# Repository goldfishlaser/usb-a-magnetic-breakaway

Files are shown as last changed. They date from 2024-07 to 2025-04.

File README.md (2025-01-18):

# usb-a-magnetic-breakaway

This repo is for documenting and providing the design requirements for an open-source USB-A magnetic breakaway connector. Originally created to be a solution for BusKill cables. Perhaps you have another reason you want to quickly magnetically detach a USB? Then here's your thing.  This project is a Work In Progress and it welcomes contributors. 

##  What's New?

Updates to goldfishlaser Version:
* Recommend using 4.0 - has latest changes with a new type of pogo receptor
* If continuing to use 3.9 be aware that there are a few issues with it that will need your attention.
* I'm giving a talk at DEF CON! Read about it here: https://crashxblossom.wordpress.com/2024/06/24/defcon32-announcement/ 

## What's in this Repo?

This repo contains full documentation for how to create this gadget. It contains documented 3D print files (SCAD and STL), Bill of Materials, and more. 



Part 1 Video Assembly Instructions: https://youtu.be/HxwEmIUqQ7w?si=xajbAuSA-TxbAlxz
Prototype Assembly Instructions: https://crashxblossom.wordpress.com/2023/07/04/exciting-milestone-in-buskill-usb-a-magnetic-release-open-hardware-project/

#### CAD Files

Directory contains CAD files for the magnetic breakway case if you want to edit the files. *(in development)*

#### STL files

Directory contains 3D print files for the magnetic breakaway case. 

#### Engineering drawings

Directory contains engineering drawings for the magnets which you can provide to a manufacturer for the purpose of ordering the magnets for the magnetic breakway.

#### Magnet_and_PP_Vendor_List.ods

File contains a list of manufacturers that sell magnets, pogo pins, and pogo receptors. 

## License

The contents of this repo are dual-licensed. All code is GPLv3 and all other content is CC-BY-SA.

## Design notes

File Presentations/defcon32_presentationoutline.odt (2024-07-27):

BusKill Defcon32 Demo Lab Outline

I. Introduction (2 mins)
  - Who is BusKill?
  - Project Goal
  - Project Rationale
II. Get to know the audience (2 mins)
  - Raise hand if
    - Have ever heard of BusKill
    - Have a 3D printer
    - Use Kali? Use QubesOS? Use Tails?
III. Software Capabilities (5 mins)
  - Lock screen / Shutdown (less than 1 min)
  - Luks Header Shredder (1 min) forensically proven with bulk extractor
  - Qubes
  - Limitations
IV. Hardware Requirements (3 mins)
  - Establishes physical security from computer to person
  - Disconnects usb easily, but not too easily
  - Able to dissemble for inspection
  - Doesn’t block neighboring ports
V. Supplier Version (1 min)
  - Components list
  - Where to find in Repo
VI. 3D-Printed Version (2 mins)
  - Components list
  - Where to find in Repo
  - Demo
VII. Hardware Development History and Philosophy (10 mins)
        - Parametric design in OpenSCAD
        - Milestones
            - Choosing parts (considerations for pogo pins, receptors, usbs)
            - Trying to splice it, frying the USB drives
            - The magnets (hexagonal, Nstrength, disc/cube)
        - Constraints
        - OpenSCAD code tour
VIII. How to help and FAQ (6 mins)
  - Build it
  - Make the case smaller
  - Make assembly easier
  - Identify cheaper and more easily sourced components
  - Make the code more parametric

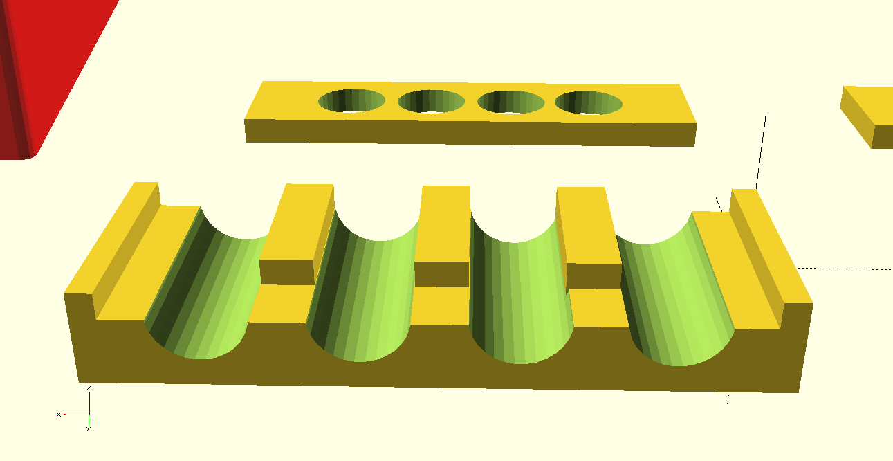
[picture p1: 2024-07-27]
CAD Files/jigdetails.png

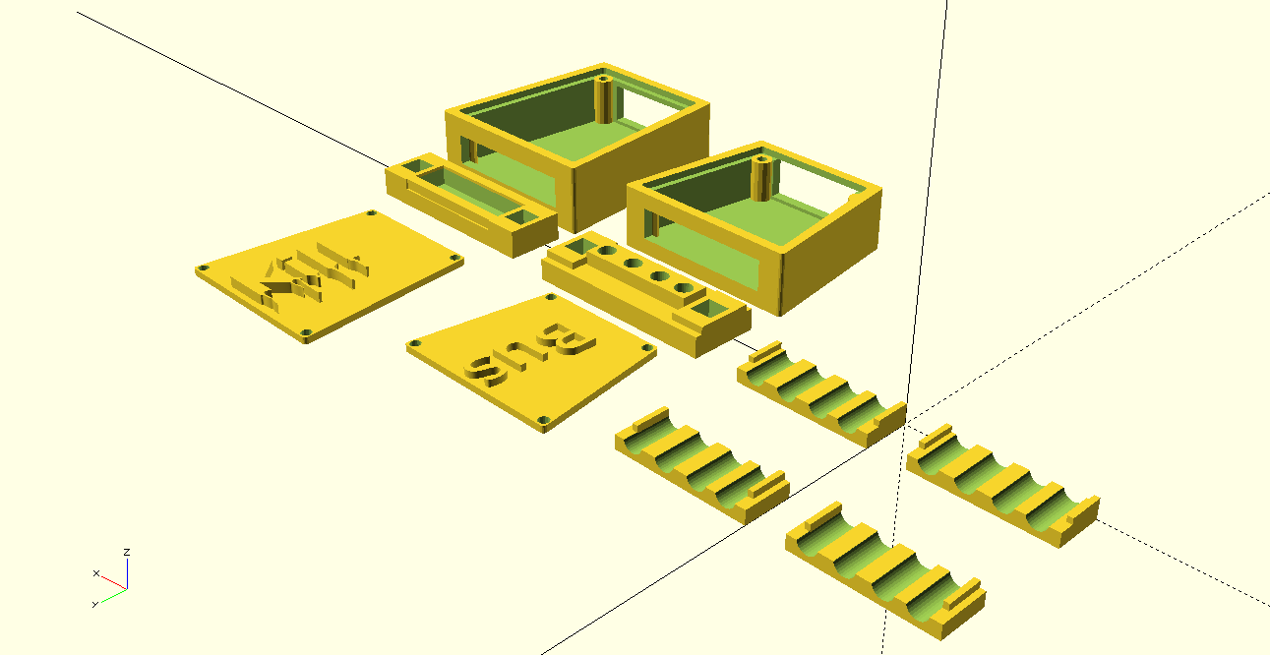
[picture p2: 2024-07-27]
CAD Files/usbamagb_v03.1b.png

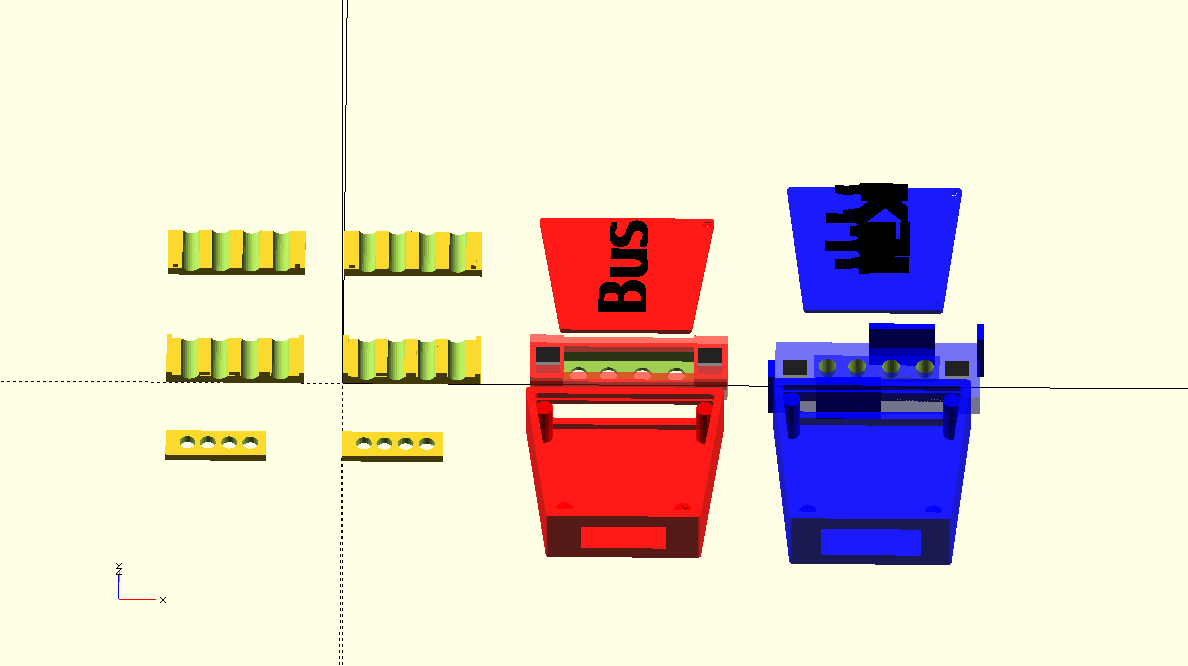
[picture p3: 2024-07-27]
CAD Files/usbamagb_v03.9.png

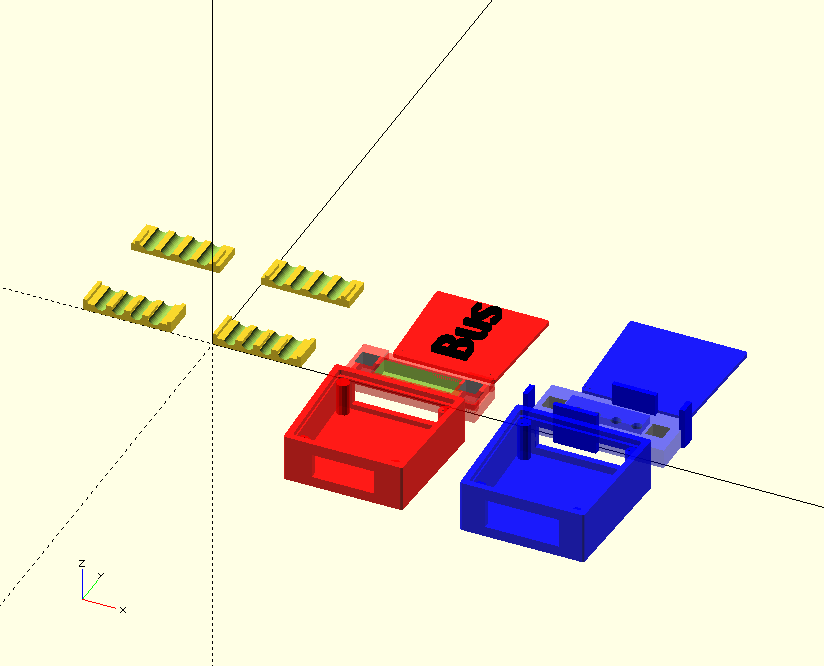
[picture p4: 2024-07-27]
digitalAssets/usbamagb_v04.0.png

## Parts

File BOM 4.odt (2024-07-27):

V 04 Bill of Materials

Open-source USB-A magnetic breakaway connector used in the BusKill laptop kill cord

This BOM is in progress

Component | Base QTY | Link (if applicable)
USB male | 1 | https://amzn.to/43tGNuv
USB female (10 mm) | 1 | https://amzn.to/43tGNuv
Pogo receptors | 4 | https://www.mouser.com/ProductDetail/Mill-Max/3024-0-01-15-00-00-03-0?qs=oyhNEzdnFLo7R2sYdNBgsw%3D%3D
Pogo pins Working height: | 4 | Option 1: https://www.digikey.com/en/products/detail/mill-max-manufacturing-corp/7973-0-15-20-77-14-11-0/10197225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 Option 2: https://www.mouser.com/ProductDetail/Mill-Max/7973-0-15-20-77-14-11-0?qs=%252B6g0mu59x7KQy9JOdoVaiw%3D%3D
3D printed release | 1 | Goldfishlaser Version/CAD Files/intermediary design files/usbamagb_v04.0.stl
3D printed breakaway | 1 | Goldfishlaser Version/CAD Files/intermediary design files/usbamagb_v04.0.stl
1/8” Cube Magnets | 8 | https://www.kjmagnetics.com/proddetail.asp?prod=B222

Estimated Cost Per Unit (without bulk price discounts)

USB Male = .14

USB female = .14

4 x pogo receptors = 4 x .32

4 x pogo pins = 4 x 1.17 (digikey)

or 4 x 1.27 (mouser)

Plastic = 13.76g / 4.61 meters = $8.76

8 x magnets = 8 x .18

USB Extension cord = $8

USB = $10

caribiner = $.80

Total =

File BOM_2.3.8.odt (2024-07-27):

V 2.3.8 Bill of Materials

Open-source USB-A magnetic breakaway connector used in the BusKill laptop kill cord

Component | Base QTY | Link (if applicable)
USB male | 1 | https://amzn.to/43tGNuv
USB female (10 mm) | 1 | https://amzn.to/43tGNuv
Pogo receptors | 4 | https://www.alibaba.com/product-detail/Circular-SMD-Contact-Pad-3-0_62437659039.html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
Pogo pins Working height: 0.298" (7.58mm) | 4 | https://www.digikey.com/en/products/detail/mill-max-manufacturing-corp/0947-0-15-20-77-14-11-0/7402798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
3D printed release | 1 | Goldfishlaser Version/CAD Files/intermediary design files/dengineering_v02.3.8.stl
3D printed breakaway | 1 | Goldfishlaser Version/CAD Files/intermediary design files/dengineering_v02.3.8.stl
3 x 4 mm Disc magnets | 8 | https://www.aliexpress.com/w/wholesale-3x4mm-neodymium-disc-magnets.html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

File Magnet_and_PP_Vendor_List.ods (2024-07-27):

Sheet: Magnets
Prototype Version | Name of Vendor | URL of product page | MOQ | Offer sample service? | Price/magnet | Sizes available (if relevant) | Comments
 |  | Cube magnets
Version >= v.3 | K&J Magnets | https://www.kjmagnetics.com/proddetail.asp?prod=B222 | 1 | N/A | 0.18 | 1/8” | Price/magnet decreases with volume size – Latest Prototype uses these – N52 gold plated may be even better
 |  | Disc magnets DO NOT USE TOO WEAK
Version 2 =< v.2.3.8 | MANHXSCY | https://www.aliexpress.us/item/2251832608106847.html | 100 | no | 0.08 | 4x3 | DO NOT USE – TOO WEAK No longer available at URL - 100pcs Neodymium N35 Dia 4mm X 3mm Strong Magnets Tiny Disc NdFeB Rare Earth For Crafts Models Fridge Sticking magnet 4x3mm
Not used | MANHXSCY | https://www.aliexpress.us/item/2251832608138260.html?gatewayAdapt=glo2usa | 50 | no | 0.175 | 5x4 | No longer available at URL - 50pcs Neodymium N35 Dia 5mm X 4mm Strong Magnets Tiny Disc NdFeB Rare Earth For Crafts Models Fridge Sticking magnet 5x4mm
 | K&J Magnets | https://www.kjmagnetics.com/proddetail.asp?prod=D101-N52 | 100 | N/A | 0.14 | 1/16" dia. x 1/32" thick
 |  | Hex magnets
 | Skyup Magnetics (Ningbo) Co., Ltd. | https://www.alibaba.com/product-detail/12-Years-Experience-factory-producing-rare_62153270553.html | 1 | N/A | $0.02-$0.60 | any
 | Xiamen Balin Magnetic Materials Co., Ltd. | https://www.alibaba.com/product-detail/Powerful-rare-earth-hexagon-neodymium-magnet_62113152666.html | 1 | N/A | $0.05 - $0.50 | any
 | Hangzhou Shengshideng Magnetics Co., Ltd. | https://www.alibaba.com/product-detail/14-Years-Experience-factory-producing-neodymium_60745639237.html | 1 | N/A | $1.00 - $10.00 | any
Version 1 | Dongguan Hj Tech Co., Ltd. | https://www.alibaba.com/product-detail/Hot-Sale-Strong-Electric-Custom-Shape_62489784248.html | 1000 | Yes | $0.03 | any | Placed order for 8 magnets of two sizes. September 9, received order October 10 The stated production time is 15-20 days, and the express delivery time is 7-9 days. There was a small delay, possibly due to holiday. (oops – didn’t realize this shop had a MoQ of 1000, but the customer service was great, and the person I worked with says I and others can order lower quantities if desired)

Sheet: Pogo Pins
Prototype Version | URL of product page | MOQ | Offer sample service? | Price/pin | Type | Comments
Version >= v.2.3.9 | https://www.digikey.com/en/products/detail/mill-max-manufacturing-corp/7973-0-15-20-77-14-11-0/10197225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 | 1 | N/A | $1.13 | 2.66mm STANDARD SPRING-LOADED PIN Contact Spring Through Hole, Solder Cup | Price decreases with order quantity; must pay shipping
Version =< v.2.3.8 | https://www.digikey.com/en/products/detail/mill-max-manufacturing-corp/0947-0-15-20-77-14-11-0/7402798 | 1 | N/A | $0.97 | 7.58mmSTANDARD SPRING-LOADED PIN CONTACT SPRING LOADED SLDR CUP | Price decreases with order quantity
Version =<v3.9 | https://www.alibaba.com/product-detail/Circular-SMD-Contact-Pad-3-0_62437659039.html | 500 | yes | $0.07 | 3.00mm radius contact pad, 2.00mm height, target pin | Ordered 11/28/2020 Received 12/16/2020
Version 4.0 | https://www.mouser.com/ProductDetail/Mill-Max/3024-0-01-15-00-00-03-0?qs=oyhNEzdnFLo7R2sYdNBgsw%3D%3D | 1 | N/A | $0.32 | Circuit Board Hardware - PCB Spring-Loaded Target Contact with Flat Face | Price decreases with order quantity; must pay shipping
Version >= v.2.3.9 | https://www.mouser.com/ProductDetail/Mill-Max/7973-0-15-20-77-14-11-0?qs=%252B6g0mu59x7KQy9JOdoVaiw%3D%3D | 1 | N/A | $1.27 | Circuit Board Hardware - PCB Spring-Loaded Pin with Solder Cup Termination | Price decreases with order quantity; must pay shipping

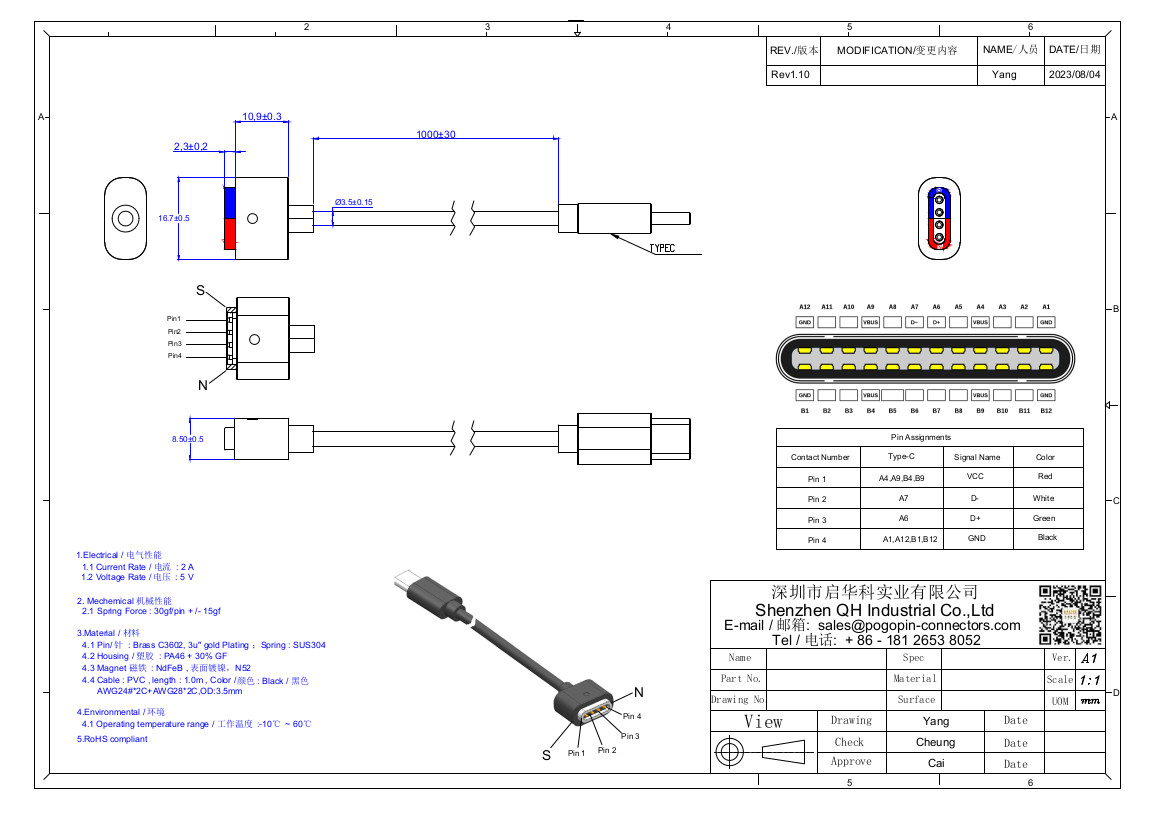
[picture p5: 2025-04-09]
supplier/shenzen_qh_industrial_co/2025-02/2025-02_buskill-usb-c-cable.jpg

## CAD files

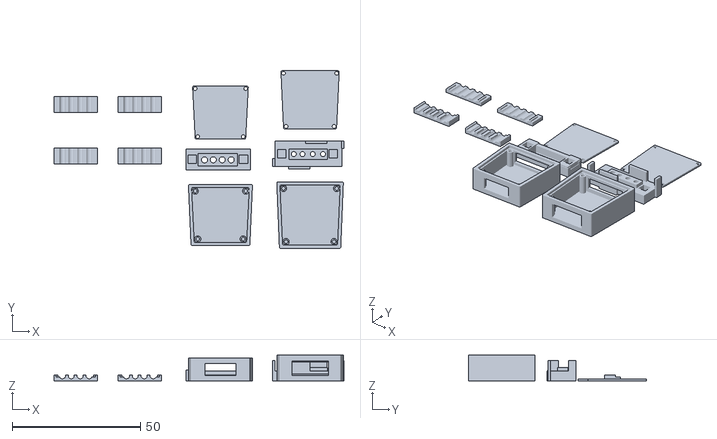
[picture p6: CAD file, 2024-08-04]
STL Files/usbamagb_v04.0.stl
113.2 x 69.4 x 10.0

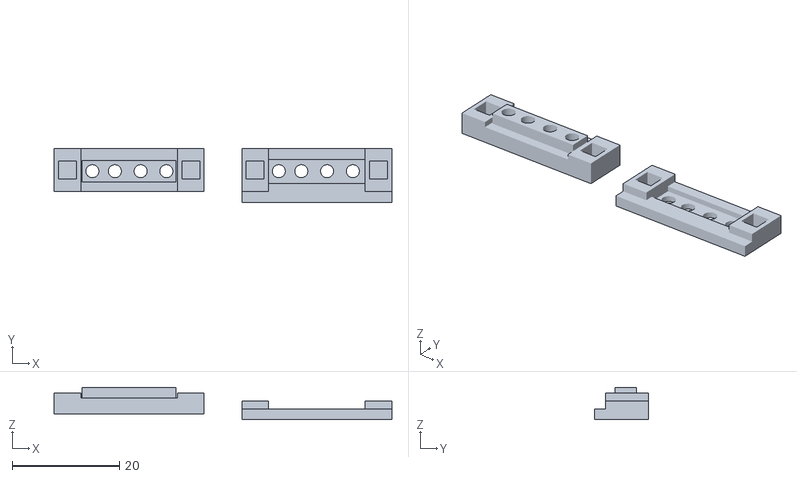
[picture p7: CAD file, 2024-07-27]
STL Files/releaseface_v03.9.stl
63.0 x 10.0 x 6.00

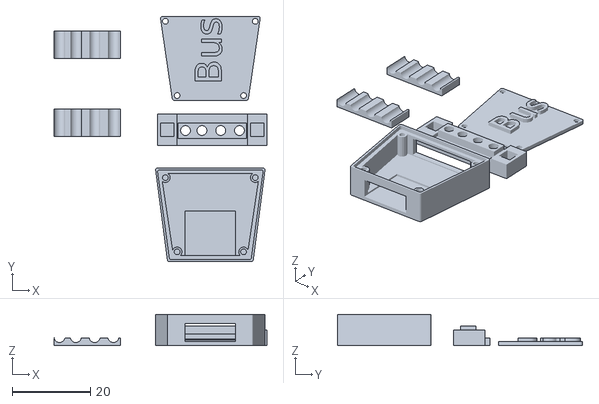
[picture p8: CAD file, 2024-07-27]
STL Files/release_v03.9.2.stl
54.5 x 62.7 x 8.00

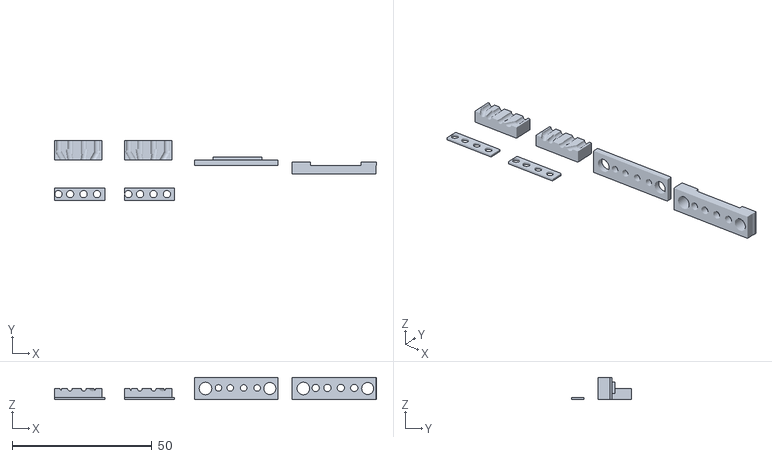
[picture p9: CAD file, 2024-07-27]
STL Files/dengineering_v02.3.9.stl
115.2 x 21.5 x 8.00

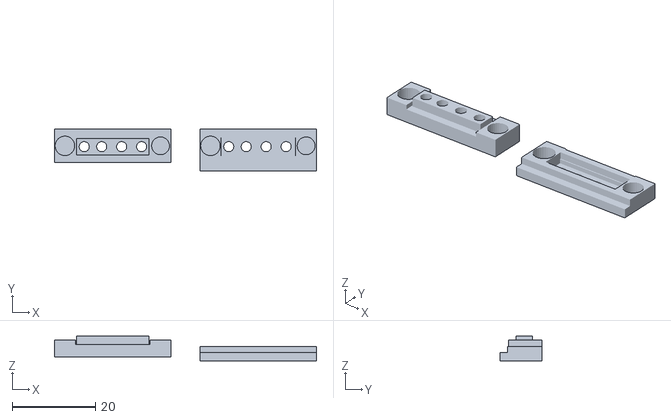
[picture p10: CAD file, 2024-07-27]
STL Files/discface_v03.9.stl
63.0 x 10.0 x 6.00

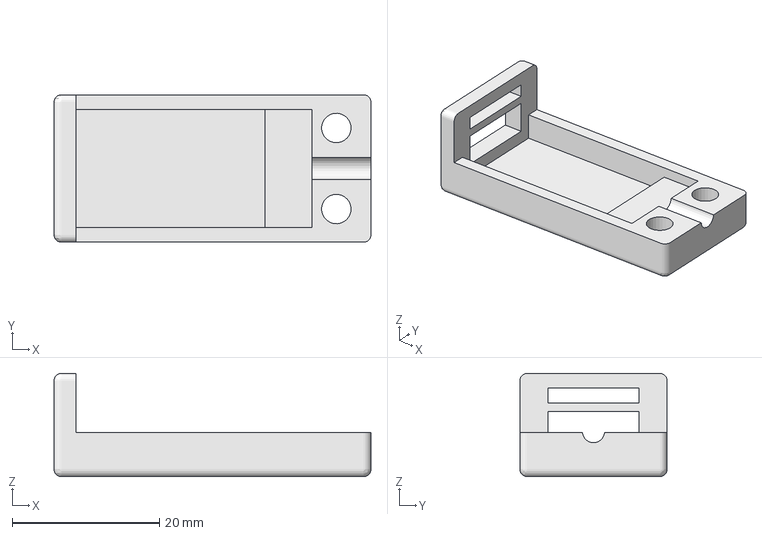
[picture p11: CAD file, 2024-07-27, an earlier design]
CAD Files/FCStd Archive/Shell_Assembly.FCStd
43.0 x 20.0 x 14.0 mm

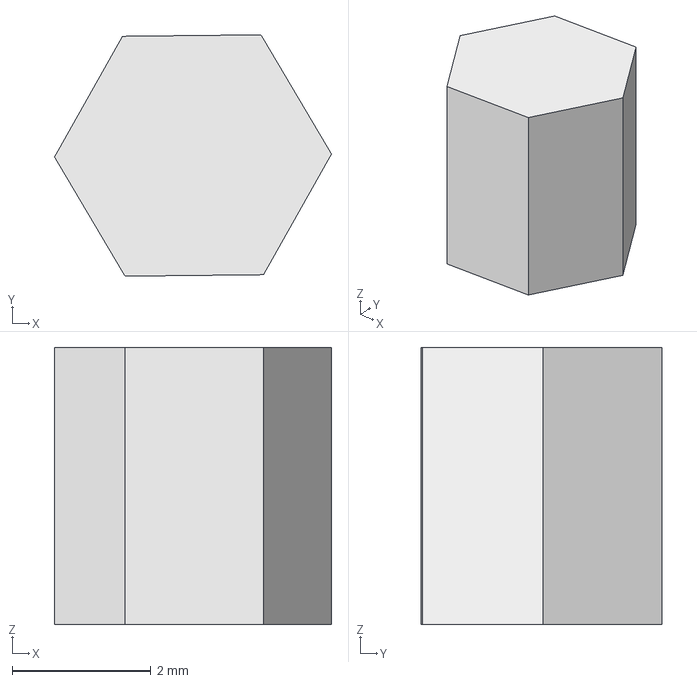
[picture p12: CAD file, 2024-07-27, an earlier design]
CAD Files/FCStd Archive/Magnet_2mm_4mm.fcstd
4.00 x 3.49 x 4.00 mm

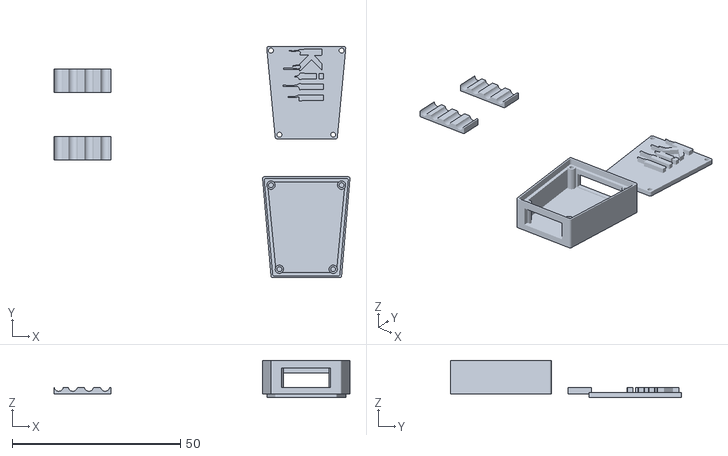
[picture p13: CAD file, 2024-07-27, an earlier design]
STL Files/STL Archive/breakaway_v03.9.stl
88.0 x 68.7 x 11.0

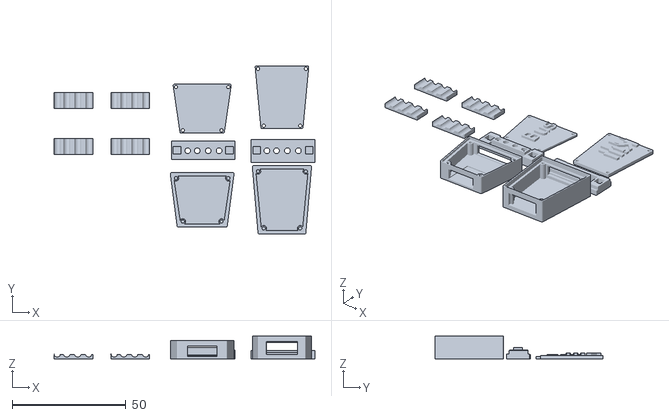
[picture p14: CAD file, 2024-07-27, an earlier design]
STL Files/usbamagb_v03.9.2.stl
114.5 x 73.7 x 10.0

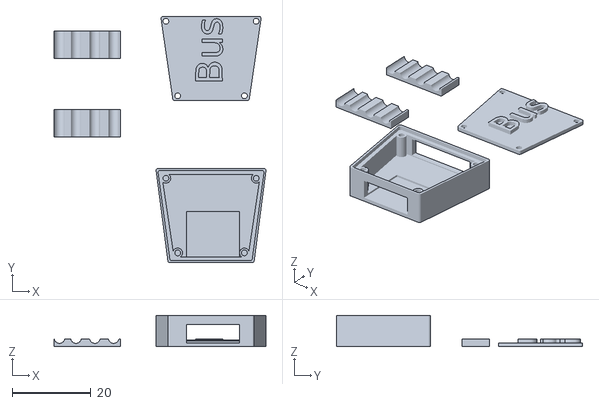
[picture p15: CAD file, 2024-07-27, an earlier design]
STL Files/release_v03.9.stl
54.0 x 62.7 x 8.00

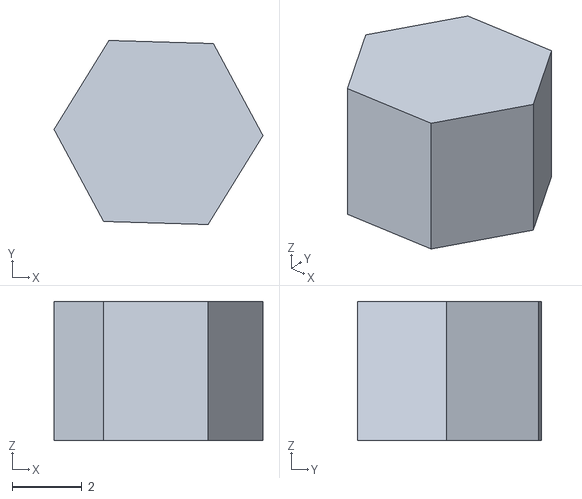
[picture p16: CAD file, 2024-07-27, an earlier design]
STL Files/STL Archive/magnet.stl
6.00 x 5.28 x 4.00

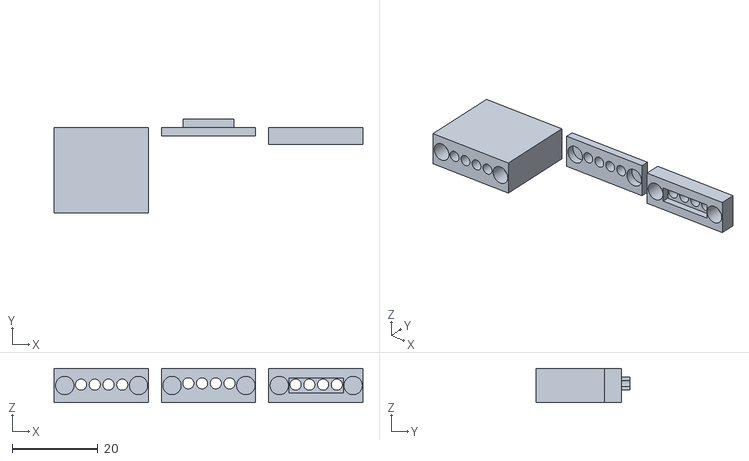
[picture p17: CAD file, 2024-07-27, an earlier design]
STL Files/STL Archive/dengineering_v01.2.stl
72.0 x 22.0 x 8.00

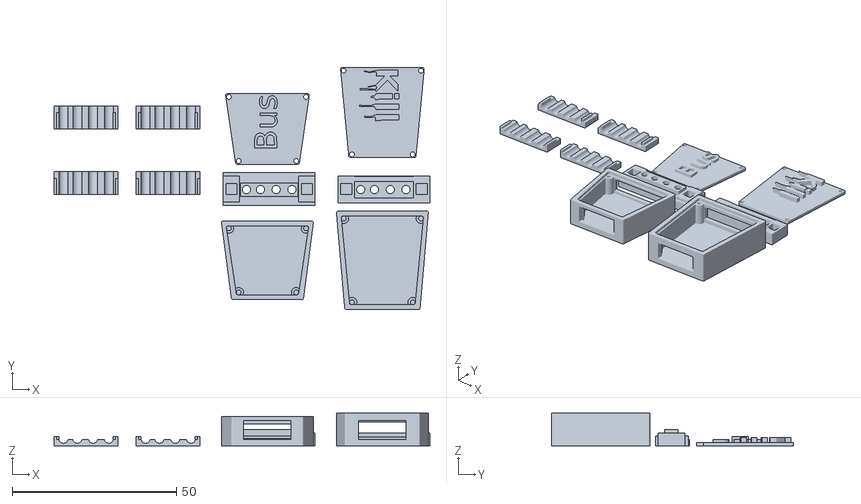
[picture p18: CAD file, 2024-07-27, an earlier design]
STL Files/usbamagb_v03.9.4.stl
114.5 x 73.7 x 10.0

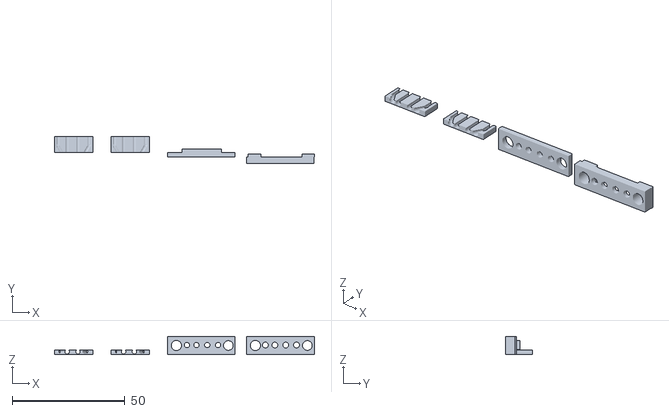
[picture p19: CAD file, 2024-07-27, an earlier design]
STL Files/STL Archive/dengineering_v02.3.3.stl
115.2 x 12.0 x 8.00

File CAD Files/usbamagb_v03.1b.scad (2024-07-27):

/*

__________ ____ ___  _____________  __.___.____    .____     
\______   \    |   \/   _____/    |/ _|   |    |   |    |    
 |    |  _/    |   /\_____  \|      < |   |    |   |    |    
 |    |   \    |  / /        \    |  \|   |    |___|    |___ 
 |_______ /______/ /_______  / ___|__ \___|_______ \_______ \
                              \/     \/           \/       \/
                                                  \/       \/   usbamagb_v03               

*/
/*                      
Buskill USB-A Magnetic breakaway Shell Assembly     
GNU General Public License v3.0 
Author: Melanie Allen
*/
    

/*
Description

BusKill is a Dead Man Switch triggered when a magnetic breakaway is tripped, severing a USB connection. This code creates a 3D printable file for plastic parts needed to create the magnetic breakaway. 

To assemble a BusKill Dead Man Switch cord you will need: a usb-a extension cord, a usb hard drive capable of being attached to a caribiner, a caribiner, the plastic pieces in this file, a usb female port, a usb male, 4 magnets, 4 pogo pins, 4 pogo receptors, wire, 8 screws, and BusKill software. For full BOM, glossary, and assembly instructions, see the files in the repo.

The magnetic breakway consists of a "breakaway" (blue) and a "release" (red). When the magnets on the breakaway and release connect, the pogo pins and pogo receptors meet and establish the USB connection. When the parts are separated, the USB connection is severed.

The "breakaway" consists of three plastic pieces. The enclosure, the lid, and the face. The face contains areas for two 1/8" cube magnets and pogo receptors. The enclosure allows for the housing of a wire jig, wires and female usb port. The lid screws onto the enclosure with 4 x 1.5-2M screws. 

The "release" consists of three plastic parts. The enclosure, the lid, and the face. The face contains areas for two 1/8" cube magnets and pogo pins. The enclosure allows for the housing of a wire jig, wires, and male usb. The release plugs into the computer. The lid screws onto the enclosure with 4 x 1.5-2M screws.

"Jigs" serve purposes such as housing wires and holding hardware in place during assembly and use. (yellow)

The code in this file is divided into five section: Parameters, Hardware, Breakaway, Release, and Assembly.
Parameters: Should you need to adjust this design to suit the parts available to you, you can tune variables for parts in this section 
Hardware: This section contains modules related to creating areas for magnets, usb, pogo pins, pogo receptors, and jigs. 
Breakaway: This section contains modules related to creating enclosure (lid, body, and face) for the breakaway. 
Release: This section contains modules related to creating the enclosure (lid, body, and face) for the release.
Assembly: This section allows you to call the modules individually or all at once. 

If you're new to openscad, might be helpful to know that numbers representing dimensions are in "mm" units. 

The assembly of the BusKill cord is as follows: (1) attach the caribiner to the usb (2) insert the USB hard drive into the female usb port in the assembled "breakaway" (3) connect the magnets of the "breakaway" to the "release" (4) insert the male usb from the "release" into the female port of the extension cable (5) insert the male end of the usb cable into the computers usb-a port. 


docs.buskill.in
buskill.in
*/

//acknowledgements to BaldGuyDIY for enclosure code

/*********** PARAMETERS ***********/

//magnet parameters 
magnet_position_x=3;
magnet_position_z=18.1;
magnet_position_y=4;
magnet_distance=23; //distance between magnets
magnet_size=3.175; // for 1/8" cube magnet
magnet_tolerance= .2; //to allow room for press fit


//USB male parameters 
u_h = 14; //height
u_w = 12; //width
u_d = 4.7; //depth 

//USB female parameters
u_f_h = 16; //height
u_f_w = 14.25; //width
u_f_d = 5.7; //depth 


//pogo parameters

pogo_length=7.6;
pogo_diameter=2.8; // pogo thickness
pogo_distance=1.5; //distance between pins 
shift=2.1; //distance from pins 
spread=4.8;
shift2=2; //distance from top

// pogo receptor parameters
size_difference = .9; // right now the code just uses pogo pin code scaled down by this variable

//jig slot variables

js_w=18+2.5;// diff=2.5 to give room for slots?
js_h=8;
js_l=4.5;


/*********** HARDWARE ***********/

//pogo pins

module pogos(){
    translate([-.3,.1,4.2]){
        
        translate([shift,0,0])
        rotate ([90,0,0])
        cylinder($fn = 30, $fa = 30, $fs = 2, h=pogo_length, r1=pogo_diameter/2, r2=pogo_diameter/2, center = true);
        
        translate([pogo_distance+spread,0,0])
        rotate ([90,0,0])
        cylinder($fn = 30, $fa = 30, $fs = 1.8, h=pogo_length, r1=pogo_diameter/2, r2=pogo_diameter/2, center = true);
            
        translate([pogo_distance+spread+spread-.5,0,0])
        rotate ([90,0,0])
        cylinder($fn = 30, $fa = 30, $fs = 2, h=pogo_length, r1=pogo_diameter/2, r2=pogo_diameter/2, center = true);
    
        translate([pogo_distance+spread*3-1,0,0])
        rotate ([90,0,0])
        cylinder($fn = 30, $fa = 30, $fs = 1.8, h=pogo_length, r1=pogo_diameter/2, r2=pogo_diameter/2, center = true);
}
}

//pogos();


// pogo receptors 

module pogo_recs(){
    translate([-.7,-.1,4.2]){
        translate([shift,0,0])rotate ([90,0,0])scale(size_difference)cylinder($fn = 30, $fa = 30, $fs = 2, h=pogo_length, r1=pogo_diameter/2, r2=pogo_diameter/2, center = true);
    translate([pogo_distance+spread,0,0])rotate ([90,0,0])scale(size_difference)cylinder($fn = 30, $fa = 30, $fs = 1.8, h=pogo_length, r1=pogo_diameter/2, r2=pogo_diameter/2, center = true);
            translate([pogo_distance+spread*2,0,0])rotate ([90,0,0])scale(size_difference)cylinder($fn = 30, $fa = 30, $fs = 2, h=pogo_length, r1=pogo_diameter/2, r2=pogo_diameter/2, center = true);
    translate([pogo_distance+spread*3,0,0])rotate ([90,0,0])scale(size_difference)cylinder($fn = 30, $fa = 30, $fs = 1.8, h=pogo_length, r1=pogo_diameter/2, r2=pogo_diameter/2, center = true);
}
}

//pogo_recs();

//usb male
module usb(){
    color("grey",.1)translate([-1,5,0])cube(size = [u_h,u_w,u_d],center=false);
}

//usb();

//usb female
module usb_p(){
    color("grey",.1)translate([-1,3.8,0])cube(size = [u_f_h,u_f_w,u_f_d],center=false);
}

//usb_p();


/** cube magnet **/
module magnet(){
color("grey") rotate ([90,0,0])translate([magnet_position_x,magnet_position_y,magnet_position_z])cube(magnet_size+magnet_tolerance, center=true);
    
   color("grey") rotate ([90,0,0])translate([magnet_position_x+magnet_distance,magnet_position_y,magnet_position_z])cube(magnet_size+magnet_tolerance,center=true);
    

}

//magnet();

/** disc magnet **/ 
module disc_magnet(){
color("grey") rotate ([90,0,0])translate([magnet_position_x,magnet_position_y,magnet_position_z])cylinder($fn = 30, $fa = 30, $fs = 2, h=4, r1=2.15+magnet_tolerance, r2=2.15+magnet_tolerance, center = true);
    
   color("grey") rotate ([90,0,0])translate([magnet_position_x+magnet_distance,magnet_position_y,magnet_position_z])cylinder($fn = 30, $fa = 30, $fs = 2, h=4, r1=2.15, r2=2.15, center = true);  

}

//disc_magnet();


// wire jigs

jig_w=19.5; //diff=2.5 to add room for slot
jig_h=2-.5;
jig_l=7;

slot_w=.75;
slot_h=jig_h/2;
slot_l=jig_l;

jigwall_w=slot_w;
jigwall_h=slot_h;
jigwall_l=jig_l-2;

var_w=1.5;
var_h=slot_h;
var_l=jig_l-2;

module var(){
    translate([spread-.1,0,var_h+.8])
    cube(size=[var_w,var_l,var_h], center=false);
    translate([spread+spread-.7,0,var_h+.8])
    cube(size=[var_w,var_l,var_h], center=false);
     translate([spread+spread+spread-1.2,0,var_h+.8])
    cube(size=[var_w,var_l,var_h], center=false);   
    
    }
    var();
    
    module var2(){
        translate([-25,0,0]){
    translate([spread-.1,0,var_h+.8])
    cube(size=[var_w,var_l,var_h], center=false);
    translate([spread+spread-.7,0,var_h+.8])
    cube(size=[var_w,var_l,var_h], center=false);
     translate([spread+spread+spread-1.2,0,var_h+.8])
    cube(size=[var_w,var_l,var_h], center=false);   
    
    }
}
var2();

module slot(){translate([0,0,slot_h])cube(size=[slot_w,slot_l,slot_h], center=false);}

module jigwall(){translate([0,0,jigwall_h+.1])cube(size=[jigwall_w,jigwall_l,jigwall_h], center=false);}

module jig(){
 j_d=20; //distance between jigs
    translate([0,0,.8])slot();
        translate([jig_w-.75,0,.8])slot();
    difference(){
        cube(size = [jig_w,jig_l,jig_h],center=false);
        translate([1.5,3.5,-2])pogos();
    } //diff 1.5 to center 
    
    translate([0,j_d,0])
  
    difference(){
        cube(size = [jig_w,jig_l,jig_h],center=false);
        translate([1.5,3.5,-2])pogos();
        ;
    } 
    translate([.75,j_d,.8])jigwall();
        translate([jig_w-1.5,j_d,.8])jigwall();
   
}
//jig();
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

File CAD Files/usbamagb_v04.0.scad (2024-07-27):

/*
 usbamagb_v04.0               
*/
/*                      
USB-A Magnetic breakaway Shell Assembly     
GNU General Public License v3.0 
Author: Melanie Allen
*/
    

/*
Description

The magnetic breakway consists of a "breakaway" (blue) and a "release" (red). When the magnets on the breakaway and release connect, the pogo pins and pogo receptors meet and establish the USB connection. When the parts are separated, the USB connection is severed.

The "breakaway" consists of three plastic pieces. The enclosure, the lid, and the face. The face contains areas for two 1/8" cube magnets and pogo receptors. The enclosure allows for the housing of a wire jig, wires and female usb port. The lid screws onto the enclosure with 4 x 1.5-2M screws. 

The "release" consists of three plastic parts. The enclosure, the lid, and the face. The face contains areas for two 1/8" cube magnets and pogo pins. The enclosure allows for the housing of a wire jig, wires, and male usb. The release plugs into the computer. The lid screws onto the enclosure with 4 x 1.5-2M screws.

"Jigs" serve purposes such as housing wires and holding hardware in place during assembly and use. (yellow)

The code in this file is divided into five section: Parameters, Hardware, Breakaway, Release, and Assembly.
Parameters: Should you need to adjust this design to suit the parts available to you, you can tune variables for parts in this section 
Hardware: This section contains modules related to creating areas for magnets, usb, pogo pins, pogo receptors, and jigs. 
Breakaway: This section contains modules related to creating enclosure (lid, body, and face) for the breakaway. 
Release: This section contains modules related to creating the enclosure (lid, body, and face) for the release.
Assembly: This section allows you to call the modules individually or all at once. 

If you're new to openscad, might be helpful to know that numbers representing dimensions are in "mm" units. 

*/

//acknowledgements to BaldGuyDIY for enclosure code

/*********** PARAMETERS ***********/

//magnet parameters 
magnet_position_x=3;
magnet_position_z=18.1;
magnet_position_y=4;
magnet_distance=20; //distance between magnets
magnet_size=3.175; // for 1/8" cube magnet
magnet_tolerance= .2; //to allow room for press fit

//r extrusion houses magnets on the release face
r_extrusion_x=4.75;//extrusion x
r_extrusion_y=1.75; //extrusion y
r_extrusion_z=8;//extrusion z


//USB male parameters 
u_h = 14; //height
u_w = 12; //width
u_d = 4.7; //depth 

//USB female parameters
u_f_h = 16; //height
u_f_w = 14.25; //width
u_f_d = 5.7; //depth 


//pogo parameters

pogo_length=9;
pogo_diameter=2.8; // pogo thickness
pogo_distance=1.5; //distance between pins 
shift=2.1; //distance from pins 
spread=4;
shift2=2; //distance from top

// pogo receptor parameters
size_difference = .7; // right now the code just uses pogo pin code scaled down by this variable

//jig slot variables

js_w=17.75;// 
js_h=8;
js_l=4.5;

//pogo house is the extrusion on the front of the breakaway face. the release face has a coresponding admission allowing for mating.
pogo_house_x = 15; //this is x
pogo_house_y = 2; // this is z
pogo_house_z =4; // this is y
pogo_house_pos_x= 31.75;
pogo_house_pos_y= 0;
pogo_house_pos_z= 2.25;

//pogo house 2 is the admission on the front of the release face. the breakaway has a corresponding extrusion allowing for mating

 pogo_house2_pos_x= pogo_house_pos_x+23.5;
 pogo_house2_pos_y= pogo_house_pos_y-r_extrusion_y-.25;
 pogo_house2_pos_z= pogo_house_pos_z;  

/*********** HARDWARE ***********/

//pogo pins

module pogos(){
    translate([-.3,.1,4.2]){
        
        translate([shift,0,0])
        rotate ([90,0,0])
        scale(.85)
        cylinder($fn = 30, $fa = 30, $fs = 2, h=pogo_length, r1=pogo_diameter/2, r2=pogo_diameter/2, center = true);
        
        translate([pogo_distance+spread,0,0])
        rotate ([90,0,0])
        scale(.85)
        cylinder($fn = 30, $fa = 30, $fs = 1.8, h=pogo_length, r1=pogo_diameter/2, r2=pogo_diameter/2, center = true);
            
        translate([pogo_distance+spread+spread-.5,0,0])
        rotate ([90,0,0])
        scale(.85)
        cylinder($fn = 30, $fa = 30, $fs = 2, h=pogo_length, r1=pogo_diameter/2, r2=pogo_diameter/2, center = true);
    
        translate([pogo_distance+spread*3-1,0,0])
        rotate ([90,0,0])
        scale(.85)
        cylinder($fn = 30, $fa = 30, $fs = 1.8, h=pogo_length, r1=pogo_diameter/2, r2=pogo_diameter/2, center = true);
}
}

//pogos();


// pogo receptors 

module pogo_recs(){
    translate([-.7,-.1,4.2]){
        translate([shift,0,0])rotate ([90,0,0])scale(size_difference)cylinder($fn = 30, $fa = 30, $fs = 2, h=pogo_length, r1=pogo_diameter/2, r2=pogo_diameter/2, center = true);
    translate([pogo_distance+spread,0,0])rotate ([90,0,0])scale(size_difference)cylinder($fn = 30, $fa = 30, $fs = 1.8, h=pogo_length, r1=pogo_diameter/2, r2=pogo_diameter/2, center = true);
            translate([pogo_distance+spread*2,0,0])rotate ([90,0,0])scale(size_difference)cylinder($fn = 30, $fa = 30, $fs = 2, h=pogo_length, r1=pogo_diameter/2, r2=pogo_diameter/2, center = true);
    translate([pogo_distance+spread*3,0,0])rotate ([90,0,0])scale(size_difference)cylinder($fn = 30, $fa = 30, $fs = 1.8, h=pogo_length, r1=pogo_diameter/2, r2=pogo_diameter/2, center = true);
}
}

//pogo_recs();

//usb male
module usb(){
    color("grey",.1)translate([-1,5,0])cube(size = [u_h,u_w,u_d],center=false);
}

//usb();

//usb female
module usb_p(){
    color("grey",.1)translate([-1,3.8,0])cube(size = [u_f_h,u_f_w,u_f_d],center=false);
}

//usb_p();


/** cube magnet **/
module magnet(){
color("grey") rotate ([90,0,0])translate([magnet_position_x,magnet_position_y,magnet_position_z])cube(magnet_size+magnet_tolerance, center=true);
    
   color("grey") rotate ([90,0,0])translate([magnet_position_x+magnet_distance,magnet_position_y,magnet_position_z])cube(magnet_size+magnet_tolerance,center=true);
    

}

//magnet();

/** disc magnet **/ 
module disc_magnet(){
color("grey") rotate ([90,0,0])translate([magnet_position_x,magnet_position_y,magnet_position_z])cylinder($fn = 30, $fa = 30, $fs = 2, h=4, r1=2.15+magnet_tolerance, r2=2.15+magnet_tolerance, center = true);
    
   color("grey") rotate ([90,0,0])translate([magnet_position_x+magnet_distance,magnet_position_y,magnet_position_z])cylinder($fn = 30, $fa = 30, $fs = 2, h=4, r1=2.15, r2=2.15, center = true);  

}

//disc_magnet();


// wire jigs

jig_w=17; //diff=2.5 to add room for slot
jig_h=2-.5;
jig_l=6.25;

slot_w=.75;
slot_h=jig_h/2;
slot_l=jig_l;

jigwall_w=slot_w;
jigwall_h=slot_h;
jigwall_l=jig_l-2;

var_w=1.25;
var_h=slot_h;
var_l=jig_l-2;

module var(){
    translate([spread+.4,0,var_h+.7])
    cube(size=[var_w,var_l,var_h], center=false);
    translate([spread+spread-.7+.5,0,var_h+.7])
    cube(size=[var_w,var_l,var_h], center=false);
     translate([spread+spread+spread-1.2+.5,0,var_h+.7])
    cube(size=[var_w,var_l,var_h], center=false);   
    
    }
 //   var();
    
    module var2(){
        translate([-25,0,0]){
    translate([spread-.1,0,var_h+.7])
    cube(size=[var_w,var_l,var_h], center=false);
    translate([spread+spread-.7,0,var_h+.7])
    cube(size=[var_w,var_l,var_h], center=false);
     translate([spread+spread+spread-1.2,0,var_h+.7])
    cube(size=[var_w,var_l,var_h], center=false);   
    
    }
}
//var2();

module slot(){translate([0,0,slot_h])cube(size=[slot_w,slot_l,slot_h], center=false);}

module jigwall(){translate([0,0,jigwall_h+.1])cube(size=[jigwall_w,jigwall_l,jigwall_h], center=false);} //change x to remove snap

module jig(){
 j_d=20; //distance between jigs
    translate([0,0,.7])slot();
        translate([jig_w-.75,0,.7])slot();
    difference(){
        cube(size = [jig_w,jig_l,jig_h],center=false);
        translate([1.5,3,-2.25])pogos();
    } //diff 1.5 to center 
    
    translate([0,j_d,0])
  
    difference(){
        cube(size = [jig_w,jig_l,jig_h],center=false);
        translate([1.5,3,-2.25])pogos();
        ;
    } 
    translate([.75,j_d,.6])jigwall(); //change x to remove snap
        translate([jig_w-1.5,j_d,.6])jigwall();
 
  var();

}
//jig();

/**
//this commented out code was used to create a wire jig that curves wire from the place where it comes out of face to where it could be soldered to a usb female or male. it didn't work well for me, but keeping the code in case it helps others or I change my mind.
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

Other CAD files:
STL Files/STL Archive/dengineering_v02.3.8.stl
STL Files/usbamagb_v03.9.1.stl
STL Files/STL Archive/dengineering_v02.2.stl
STL Files/STL Archive/mag_startover_v0.2.stl
CAD Files/dengineering_v02.3.scad
CAD Files/usbamagb_v03.1.scad
CAD Files/SCAD Archive/dengineering_v01.1.scad
CAD Files/SCAD Archive/dengineering_v01.scad
CAD Files/SCAD Archive/dengineering_v02.scad
CAD Files/SCAD Archive/mag_release_diskmag_v0.1.scad
CAD Files/SCAD Archive/mag_startover_v0.1.scad
CAD Files/SCAD Archive/mag_startover_v0.2.scad
CAD Files/SCAD Archive/magnetic_release_0.7.scad
CAD Files/SCAD Archive/magnetic_release_v0.8.scad
CAD Files/SCAD Archive/magnetic_release_v0.9.scad
CAD Files/usbamagb_v03.2.scad
CAD Files/usbamagb_v03.9.scad
CAD Files/usbamagb_v03.scad
CAD Files/usbamagb_v04.0.stl
STL Files/STL Archive/breakaway_v03.9.1.stl
STL Files/STL Archive/breakaway_v03.9.2.stl
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

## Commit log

2024-07-27 organizing files
    [Magnet_2mm_4mm.fcstd, Magnet_and_PP_Vendor_List.ods, Shell_Assembly.FCStd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]
2024-07-27 removing unnecessary files
    [buskill_usba_magnetic_breakaway_cable.FCStd, buskill_usba_magnetic_breakaway_cable_2.FCStd, buskill_usba_magnetic_breakaway_cable_4.FCStd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]
2024-07-27 remove buskill logo
    [usbamagb_v04.0.scad, usbamagb_v04.0.stl]
2024-07-27 getting ready for def con
    [usbamagb_v04.0.scad]
2024-08-04 latest version
    [usbamagb_v04.0.stl]
